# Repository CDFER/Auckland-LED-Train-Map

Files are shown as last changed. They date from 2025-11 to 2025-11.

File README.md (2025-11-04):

# Auckland Live LED Train Map




**You can now support my work by buying this through my store:** [**https://keastudios.co.nz/store/akl-ltm/**](https://keastudios.co.nz/store/akl-ltm/)

A physical, real-time LED map of the Auckland train network, powered by an ESP32-C3 microcontroller. Train movements are displayed using addressable RGB LEDs, with live data fetched over Wi-Fi.

---

## Table of Contents

- [Auckland Live LED Train Map](#auckland-live-led-train-map)
  - [Table of Contents](#table-of-contents)
  - [Features](#features)
  - [Hardware](#hardware)
  - [PCB Design](#pcb-design)
  - [Software / Firmware](#software--firmware)
  - [Getting Started](#getting-started)
  - [Web Installer](#web-installer)
  - [Links](#links)
  - [Contributing](#contributing)
  - [License](#license)

---

PCB Overview Render

## Features

- **Real-time Train Tracking:** Displays the approximate locations of trains on the Auckland network.
- **Addressable LEDs:** ~150 WS2812B-compatible RGB LEDs (1.6x1.5mm) for a vibrant display.
- **Wi-Fi Connectivity:** ESP32-C3's built-in Wi-Fi fetches live train data.
- **Custom PCB:** Designed for JLCPCB manufacturing limits.
- **Open Source:** Hardware and firmware are open source.

---

## Hardware

- **Microcontroller:** ESP32-C3 (RISC-V, 160 MHz, 4 MB Flash, QFN32)
- **LEDs:** ~150 x XL-1615RGBC-WS2812B (1.6mm x 1.5mm)
- **PCB:** 249mm x 66mm, JLCPCB-friendly
- **Antenna:** On-board PCB antenna ([TI CC2430DB design](https://www.ti.com/lit/ug/swru125/swru125.pdf))

ESP32-C3 PCB Render

Pukekohe PCB Render

---

## PCB Design

- Designed in **KiCad V9.0** using [JLCPCB KiCad Library](https://github.com/CDFER/jlcpcb-kicad-library)
- **View Online:** [Interactive PCB Layout (Kicanvas)](https://kicanvas.org/?github=https%3A%2F%2Fgithub.com%2FCDFER%2FAuckland-LED-Train-Map%2Ftree%2Fmain%2FPCB)
- **Source Files:** `/PCB` directory

Schematic

---

## Software / Firmware

The firmware has been moved to it own repo now and can be found here: [LED-Rails-Firmware](https://github.com/CDFER/LED-Rails-Firmware)

---

## Getting Started

1. **Flash the Firmware:**
   - Use the [Web Installer](https://cdfer.github.io/LED-Rails-Firmware/led-rails.html) (recommended, no drivers needed)
2. **Connect to Wi-Fi:**
   - On first boot, use the web interface to configure Wi-Fi credentials.
3. **Power the Board:**
   - Use a 5V USB-C power supply capable of at least 1A.
4. **Enjoy the Live Map!**

---

## Web Installer

Easily flash the latest firmware to your ESP32-C3 using your browser:

[Open the LED Rails Web Installer](https://cdfer.github.io/LED-Rails-Firmware/led-rails.html)

- Works with Chrome, Edge, or any Web Serial-compatible browser
- Follow on-screen instructions to connect and flash your device

---

## Links

- [Web Installer](https://cdfer.github.io/LED-Rails-Firmware/led-rails.html)
- [Interactive PCB Viewer](https://kicanvas.org/?github=https%3A%2F%2Fgithub.com%2FCDFER%2FAuckland-LED-Train-Map%2Ftree%2Fmain%2FPCB)
- [GTFS Realtime Cache API](https://github.com/CDFER/GTFS-Realtime-Cache-Server)
- [JLCPCB KiCad Library](https://github.com/CDFER/jlcpcb-kicad-library)

---

## Contributing

Contributions are welcome! Open an issue or submit a pull request for improvements, bug fixes, or feature suggestions.

---

## License

This project is released under the GPL-3.0-or-later license.

© 2025 Chris Dirks

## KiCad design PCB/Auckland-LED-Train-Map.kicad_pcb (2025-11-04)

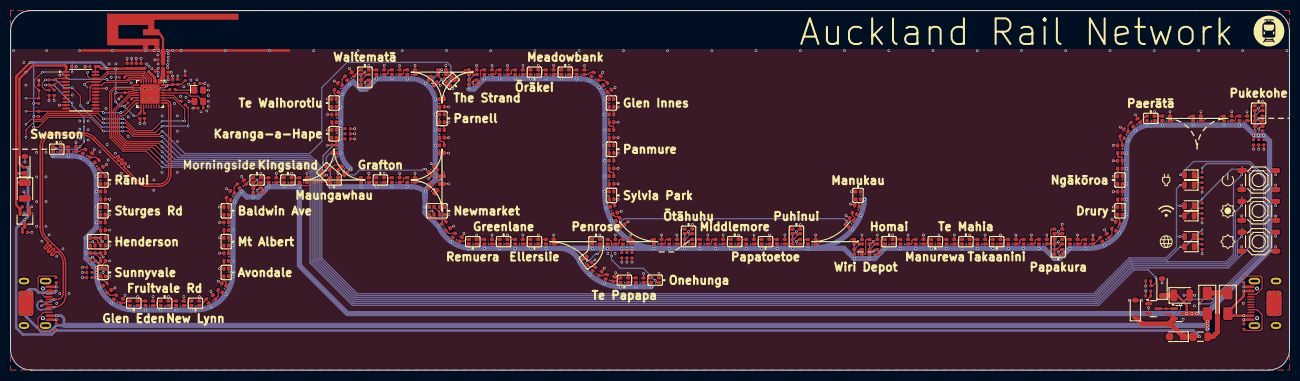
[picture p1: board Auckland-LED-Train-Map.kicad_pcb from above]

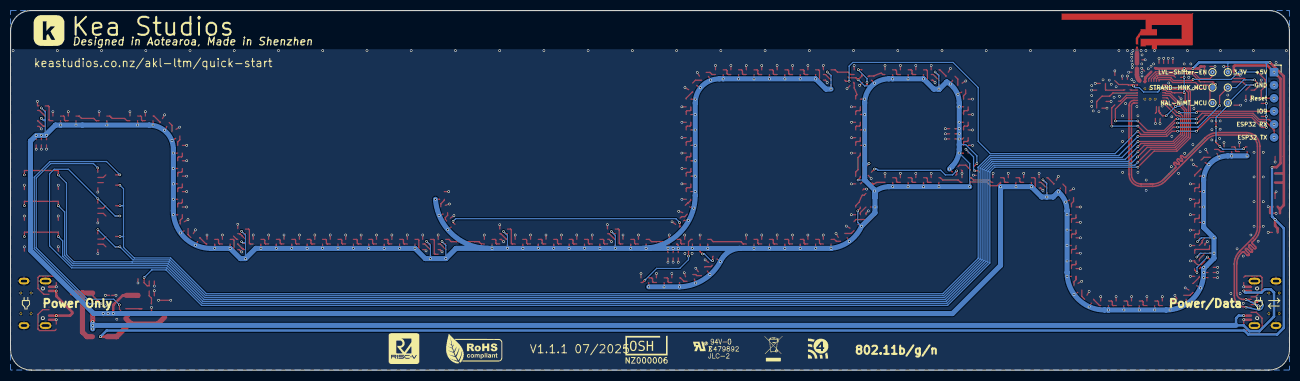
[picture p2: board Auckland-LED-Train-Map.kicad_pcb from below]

Board: 2 copper layers, 249.0 x 70.0 mm, 248 parts (7 on the bottom side), 199 nets.

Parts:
AE1: Antenna_Shield; Inverted_F_Antenna_2.4Ghz_1.0mmPCB_TI_CC2430DB.pretty
C1: 10uF; C_CASE-A-3216-18(mm)
C2, C3, C4, C6, C7, C8, C9, C10, C11, C12, C13, C14, C18, C21, C22, C25, C26, C27, C28, C29, C30, C31, C35, C38, C39, C40, C41, C42, C43: 1uF; C_0402
C5, C15: 100uF; C_CASE-B-3528-21(mm)
C19, C20: 27pF; C_0402
C36, C37: 1.5pF; C_0402
D1: MMSZ5227B; D_SOD-123
D2, D10, D11: Red; D_0805
D4, D5: MM1W5V6; D_SOD-123
D6, D7: SS54; D_SMA
D8, D9, D12: Green; D_0805
D13: H3V3U10B; D_DFN1006-2L
D100, D101, D102, D103, D104, D105, D106, D107, D108, D109, D110, D111, D112, D113, D114, D115, D116, D117, D118, D119, D120, D121, D122, D123, D124, D125, D126, D127, D128, D129, D130, D131, D132, D133, D134, D135, D136, D137, D138, D139, D140, D141, D142, D143, D144, D145, D146, D147, D148, D149, D150, D151, D152, D153, D154, D155, D156, D157, D158, D159, D160, D161, D162, D163, D164, D165, D166, D167, D168, D169, D170, D171, D172, D173, D174, D175, D176, D177, D178, D179, D180, D181, D182, D183, D184, D185, D186, D187, D188, D189, D190, D191, D192, D193, D194, D195, D196, D197, D198, D199, D200, D201, D202, D203, D204, D205, D206, D207, D208, D300, D301, D302, D303, D304, D305, D306, D307, D308, D309, D310, D311, D312, D313, D314, D315, D316, D317, D318, D319, D320, D321, D322, D323, D324, D325, D326, D327, D328, D329, D330, D331, D332, D333, D334, D335, D336, D337, D338, D339, D340, D341, D342, D343, D344: XL-1615RGBC-WS2812B-S; LED-SMD_4P-L1.6-W1.5_XL-1615RGBC-WS2812B
F1: Polyfuse, 2A; Fuse_1206_3216Metric
J1: Prog Connector
L1, L3: 2.7nH; L_0402
L5: 15nH,300mA; L_0402
LOGO1: OSHW-Certification-Mark-Stacked_8x7mm_SilkMask
Q1: HL3415A; Q_SOT-23
Q2: MMBT3904; Q_SOT-23
R1, R2, R3, R4, R8, R12, R17, R21: 10kΩ; R_0402
R7, R18: 510Ω; R_0402
R9, R16, R22, R23, R24, R25: 100kΩ; R_0402
R10, R15: 100Ω; R_0402
R13, R14, R19, R20: 5.1kΩ; R_0402
S1, S2, S3: Tactile Button, 160gf; SW-SMD_4P-L5.1-W5.1-P3.70-LS6.5-TL-2
TP2: NAL-NIMT_MCU; TestPoint_Pad_D1.0mm
TP3: NAL-NIMT_LED; TestPoint_Pad_D1.0mm
TP8: STRAND-MNK_MCU; TestPoint_Pad_D1.0mm
TP9: STRAND-MNK_LED; TestPoint_Pad_D1.0mm
TP13: 3.3V; TestPoint_Pad_D1.0mm
TP15: LVL-Shifter-EN; TestPoint_Pad_D1.0mm
U1: XC6206P332MR; SOT-23-3_L2.9-W1.6-P1.90-LS2.8-BR
U2: ESP32-C3FH4; QFN-32-1EP_5x5mm_P0.5mm_EP3.7x3.7mm_ThermalVias
U3: SN74LVC4245APWR; TSSOP-24_4.4x7.8mm_P0.65mm
U4, U5: Connector, USB-TYPE-C-16P; TYPE-C-SMD_HX-TYPE-C-16PIN
X1: 40MHz, 15pF; OSC-SMD_4P-L3.2-W2.5-BL_SIT8008BI

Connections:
+3V3: C3.1, C4.1, C5.1, C6.1, C8.1, C9.1, C10.1, C11.1, C12.1, C13.1, C22.1, C25.1, D1.1, D8.2, D10.2, D11.2, L3.1, R1.1, R2.1, R3.1, R4.1, TP13.1, U1.2 (VOUT), U2.11 (VDD3P3_RTC), U2.17 (VDD3P3_CPU), U2.31 (VDDA), U2.32 (VDDA), U3.23 (VCCB(3V)), U3.24 (VCCB(3V))
+5V: C15.1, C26.1, C27.1, C28.1, C29.1, C30.1, C31.1, C38.1, C39.1, C40.1, C41.1, C42.1, C43.1, D4.1, D100.2 (VDD), D101.2 (VDD), D102.2 (VDD), D103.2 (VDD), D104.2 (VDD), D105.2 (VDD), D106.2 (VDD), D107.2 (VDD), D108.2 (VDD), D109.2 (VDD), D110.2 (VDD), D111.2 (VDD), D112.2 (VDD), D113.2 (VDD), D114.2 (VDD), D115.2 (VDD), D116.2 (VDD), D117.2 (VDD), D118.2 (VDD), D119.2 (VDD), D120.2 (VDD), D121.2 (VDD), D122.2 (VDD), D123.2 (VDD), D124.2 (VDD), D125.2 (VDD), D126.2 (VDD), D127.2 (VDD), D128.2 (VDD), D129.2 (VDD), D130.2 (VDD), D131.2 (VDD), D132.2 (VDD), D133.2 (VDD), D134.2 (VDD), D135.2 (VDD), D136.2 (VDD), D137.2 (VDD), D138.2 (VDD), D139.2 (VDD), D140.2 (VDD), D141.2 (VDD), D142.2 (VDD), D143.2 (VDD), D144.2 (VDD), D145.2 (VDD), D146.2 (VDD), D147.2 (VDD), D148.2 (VDD), D149.2 (VDD), D150.2 (VDD), D151.2 (VDD), D152.2 (VDD), D153.2 (VDD), D154.2 (VDD), D155.2 (VDD), D156.2 (VDD), D157.2 (VDD), D158.2 (VDD), D159.2 (VDD), D160.2 (VDD), D161.2 (VDD), D162.2 (VDD), D163.2 (VDD), D164.2 (VDD), D165.2 (VDD), D166.2 (VDD), D167.2 (VDD), D168.2 (VDD), D169.2 (VDD), D170.2 (VDD), D171.2 (VDD), D172.2 (VDD), D173.2 (VDD), D174.2 (VDD), D175.2 (VDD), D176.2 (VDD), D177.2 (VDD), D178.2 (VDD), D179.2 (VDD), D180.2 (VDD), D181.2 (VDD), D182.2 (VDD), D183.2 (VDD), D184.2 (VDD), D185.2 (VDD), D186.2 (VDD), D187.2 (VDD), D188.2 (VDD), D189.2 (VDD), D190.2 (VDD), D191.2 (VDD), D192.2 (VDD), D193.2 (VDD), D194.2 (VDD), D195.2 (VDD), D196.2 (VDD), D197.2 (VDD), D198.2 (VDD), D199.2 (VDD), D200.2 (VDD), D201.2 (VDD), D202.2 (VDD), D203.2 (VDD), D204.2 (VDD), D205.2 (VDD), D206.2 (VDD), D207.2 (VDD), D208.2 (VDD), D300.2 (VDD), D301.2 (VDD), D302.2 (VDD), D303.2 (VDD), D304.2 (VDD), D305.2 (VDD), D306.2 (VDD), D307.2 (VDD), D308.2 (VDD), D309.2 (VDD), D310.2 (VDD), D311.2 (VDD), D312.2 (VDD), D313.2 (VDD), D314.2 (VDD), D315.2 (VDD), D316.2 (VDD), D317.2 (VDD), D318.2 (VDD), D319.2 (VDD), D320.2 (VDD), D321.2 (VDD), D322.2 (VDD), D323.2 (VDD), D324.2 (VDD), D325.2 (VDD), D326.2 (VDD), D327.2 (VDD), D328.2 (VDD), D329.2 (VDD), D330.2 (VDD), D331.2 (VDD), D332.2 (VDD), D333.2 (VDD), D334.2 (VDD), D335.2 (VDD), D336.2 (VDD), D337.2 (VDD), D338.2 (VDD), D339.2 (VDD), D340.2 (VDD), D341.2 (VDD), D342.2 (VDD), D343.2 (VDD), D344.2 (VDD), Q1.3 (D)
/+BRIGHTNESS_BUTTON: S2.1 (A), S2.2 (B), U2.13 (MTDO)
/-BRIGHTNESS_BUTTON: S3.1 (A), S3.2 (B), U2.12 (MTCK)
/Antenna: C36.1, D13.2, L1.1, U2.1 (LNA_IN)
/BOOT_IO9_BUTTON: J1.4, R1.2, S1.1 (A), S1.2 (B), U2.15 (GPIO9)
/CONFIG_LED: D12.2, R21.1, U2.10 (MTDI)
/D+: U2.26 (GPIO19/USB_D+), U4.A6 (D+), U4.B6 (D+)
/D-: U2.25 (GPIO18/USB_D-), U4.A7 (D-), U4.B7 (D-)
/LED_+5V_EN_Active_High: R17.1, R18.1, U2.9 (MTMS)
/LVL_Shifter_EN_Active_Low: TP15.1, U2.4 (GPIO0/XTAL_32K_P), U3.22 (OE#)
/MCU_RX: J1.5, U2.27 (U0RXD)
/MCU_TX: J1.6, R7.1
/NAL-NIMT_MCU: TP2.1, U2.8 (GPIO3), U3.20 (B2)
/Reset: C14.1, J1.3, R4.2, U2.7 (CHIP_EN)
/STRAND-MNK_MCU: TP8.1, U2.5 (GPIO1/XTAL_32K_N), U3.21 (B1)
/WIFI_LED: D9.2, R8.1, U2.16 (GPIO10)
GND: AE1.2 (Shield), C1.2, C2.2, C3.2, C4.2, C5.2, C6.2, C7.2, C8.2, C9.2, C10.2, C11.2, C12.2, C13.2, C14.2, C15.2, C18.2, C19.1, C20.2, C21.2, C22.2, C25.2, C26.2, C27.2, C28.2, C29.2, C30.2, C31.2, C35.2, C36.2, C37.2, C38.2, C39.2, C40.2, C41.2, C42.2, C43.2, D1.2, D4.2, D5.2, D13.1, D100.3 (GND), D101.3 (GND), D102.3 (GND), D103.3 (GND), D104.3 (GND), D105.3 (GND), D106.3 (GND), D107.3 (GND), D108.3 (GND), D109.3 (GND), D110.3 (GND), D111.3 (GND), D112.3 (GND), D113.3 (GND), D114.3 (GND), D115.3 (GND), D116.3 (GND), D117.3 (GND), D118.3 (GND), D119.3 (GND), D120.3 (GND), D121.3 (GND), D122.3 (GND), D123.3 (GND), D124.3 (GND), D125.3 (GND), D126.3 (GND), D127.3 (GND), D128.3 (GND), D129.3 (GND), D130.3 (GND), D131.3 (GND), D132.3 (GND), D133.3 (GND), D134.3 (GND), D135.3 (GND), D136.3 (GND), D137.3 (GND), D138.3 (GND), D139.3 (GND), D140.3 (GND), D141.3 (GND), D142.3 (GND), D143.3 (GND), D144.3 (GND), D145.3 (GND), D146.3 (GND), D147.3 (GND), D148.3 (GND), D149.3 (GND), D150.3 (GND), D151.3 (GND), D152.3 (GND), D153.3 (GND), D154.3 (GND), D155.3 (GND), D156.3 (GND), D157.3 (GND), D158.3 (GND), D159.3 (GND), D160.3 (GND), D161.3 (GND), D162.3 (GND), D163.3 (GND), D164.3 (GND), D165.3 (GND), D166.3 (GND), D167.3 (GND), D168.3 (GND), D169.3 (GND), D170.3 (GND), D171.3 (GND), D172.3 (GND), D173.3 (GND), D174.3 (GND), D175.3 (GND), D176.3 (GND), D177.3 (GND), D178.3 (GND), D179.3 (GND), D180.3 (GND), D181.3 (GND), D182.3 (GND), D183.3 (GND), D184.3 (GND), D185.3 (GND), D186.3 (GND), D187.3 (GND), D188.3 (GND), D189.3 (GND), D190.3 (GND), D191.3 (GND), D192.3 (GND), D193.3 (GND), D194.3 (GND), D195.3 (GND), D196.3 (GND), D197.3 (GND), D198.3 (GND), D199.3 (GND), D200.3 (GND), D201.3 (GND), D202.3 (GND), D203.3 (GND), D204.3 (GND), D205.3 (GND), D206.3 (GND), D207.3 (GND), D208.3 (GND), D300.3 (GND), D301.3 (GND), D302.3 (GND), D303.3 (GND), D304.3 (GND), D305.3 (GND), D306.3 (GND), D307.3 (GND), D308.3 (GND), D309.3 (GND), D310.3 (GND), D311.3 (GND), D312.3 (GND), D313.3 (GND), D314.3 (GND), D315.3 (GND), D316.3 (GND), D317.3 (GND), D318.3 (GND), D319.3 (GND), D320.3 (GND), D321.3 (GND), D322.3 (GND), D323.3 (GND), D324.3 (GND), D325.3 (GND), D326.3 (GND), D327.3 (GND), D328.3 (GND), D329.3 (GND), D330.3 (GND), D331.3 (GND), D332.3 (GND), D333.3 (GND), D334.3 (GND), D335.3 (GND), D336.3 (GND), D337.3 (GND), D338.3 (GND), D339.3 (GND), D340.3 (GND), D341.3 (GND), D342.3 (GND), D343.3 (GND), D344.3 (GND), J1.2, Q2.2 (E), R9.2, R13.2, R14.2, R17.2, R19.2, R20.2, R22.2, R23.2, R24.2, R25.2, S1.3 (C), S1.4 (D), S2.3 (C), S2.4 (D), S3.3 (C), S3.4 (D), U1.1 (GND), U2.33 (GND), U3.2 (DIR), U3.11 (GND), U3.12 (GND), U3.13 (GND), U3.14 (B8), U3.15 (B7), U3.16 (B6), U3.17 (B5), U3.18 (B4), U3.19 (B3), U4.A12B1 (GND), U4.B12A1 (GND), U4.S1 (SHIELD), U5.A12B1 (GND), U5.B12A1 (GND), U5.S1 (SHIELD), X1.2 (GND), X1.4 (GND)
NAL-NIMT-1: D100.4 (DIN), R10.1, R24.1, TP3.1
NAL-NIMT-2: D135.1 (DOUT), D136.4 (DIN)
NAL-NIMT-3: D165.1 (DOUT), D166.4 (DIN)
NAL-NIMT-4: D192.1 (DOUT), D193.4 (DIN)
unnamed: AE1.1 (A), C37.1, L1.2
unnamed: C7.1, L3.2, U2.2 (VDD3P3), U2.3 (VDD3P3)
unnamed: C20.1, L5.1, X1.1 (OSC)
unnamed: D2.1, R12.1
unnamed: D2.2, D6.1, D7.1, F1.1
unnamed: D6.2, U4.A9B4 (VBUS), U4.B9A4 (VBUS)
unnamed: D7.2, U5.A9B4 (VBUS), U5.B9A4 (VBUS)
unnamed: D8.1, R9.1
unnamed: D9.1, R22.1
unnamed: D10.1, R8.2
unnamed: D11.1, R21.2
unnamed: D12.1, R23.1
unnamed: D100.1 (DOUT), D101.4 (DIN)
unnamed: D101.1 (DOUT), D102.4 (DIN)
unnamed: D102.1 (DOUT), D103.4 (DIN)
unnamed: D103.1 (DOUT), D104.4 (DIN)
unnamed: D104.1 (DOUT), D105.4 (DIN)
unnamed: D105.1 (DOUT), D106.4 (DIN)
unnamed: D106.1 (DOUT), D107.4 (DIN)
unnamed: D107.1 (DOUT), D108.4 (DIN)
unnamed: D108.1 (DOUT), D109.4 (DIN)
unnamed: D109.1 (DOUT), D110.4 (DIN)
unnamed: D110.1 (DOUT), D111.4 (DIN)
unnamed: D111.1 (DOUT), D112.4 (DIN)
unnamed: D112.1 (DOUT), D113.4 (DIN)
unnamed: D113.1 (DOUT), D114.4 (DIN)
unnamed: D114.1 (DOUT), D115.4 (DIN)
unnamed: D115.1 (DOUT), D116.4 (DIN)
unnamed: D116.1 (DOUT), D117.4 (DIN)
unnamed: D117.1 (DOUT), D118.4 (DIN)
unnamed: D118.1 (DOUT), D119.4 (DIN)
unnamed: D119.1 (DOUT), D120.4 (DIN)
unnamed: D120.1 (DOUT), D121.4 (DIN)
unnamed: D121.1 (DOUT), D122.4 (DIN)
unnamed: D122.1 (DOUT), D123.4 (DIN)
unnamed: D123.1 (DOUT), D124.4 (DIN)
unnamed: D124.1 (DOUT), D125.4 (DIN)
unnamed: D125.1 (DOUT), D126.4 (DIN)
unnamed: D126.1 (DOUT), D127.4 (DIN)
unnamed: D127.1 (DOUT), D128.4 (DIN)
unnamed: D128.1 (DOUT), D129.4 (DIN)
unnamed: D129.1 (DOUT), D130.4 (DIN)
unnamed: D130.1 (DOUT), D131.4 (DIN)
unnamed: D131.1 (DOUT), D132.4 (DIN)
unnamed: D132.1 (DOUT), D133.4 (DIN)
unnamed: D133.1 (DOUT), D134.4 (DIN)
unnamed: D134.1 (DOUT), D135.4 (DIN)
unnamed: D136.1 (DOUT), D137.4 (DIN)
unnamed: D137.1 (DOUT), D138.4 (DIN)
unnamed: D138.1 (DOUT), D139.4 (DIN)
unnamed: D139.1 (DOUT), D140.4 (DIN)
unnamed: D140.1 (DOUT), D141.4 (DIN)
unnamed: D141.1 (DOUT), D142.4 (DIN)
unnamed: D142.1 (DOUT), D143.4 (DIN)
unnamed: D143.1 (DOUT), D144.4 (DIN)
unnamed: D144.1 (DOUT), D145.4 (DIN)
unnamed: D145.1 (DOUT), D146.4 (DIN)
unnamed: D146.1 (DOUT), D147.4 (DIN)
unnamed: D147.1 (DOUT), D148.4 (DIN)
unnamed: D148.1 (DOUT), D149.4 (DIN)
unnamed: D149.1 (DOUT), D150.4 (DIN)
unnamed: D150.1 (DOUT), D151.4 (DIN)
unnamed: D152.1 (DOUT), D153.4 (DIN)
unnamed: D153.1 (DOUT), D154.4 (DIN)
unnamed: D154.1 (DOUT), D155.4 (DIN)
unnamed: D155.1 (DOUT), D156.4 (DIN)
unnamed: D157.1 (DOUT), D158.4 (DIN)
unnamed: D158.1 (DOUT), D159.4 (DIN)
unnamed: D159.1 (DOUT), D160.4 (DIN)
unnamed: D160.1 (DOUT), D161.4 (DIN)
unnamed: D161.1 (DOUT), D162.4 (DIN)
unnamed: D162.1 (DOUT), D163.4 (DIN)
unnamed: D163.1 (DOUT), D164.4 (DIN)
unnamed: D164.1 (DOUT), D165.4 (DIN)
unnamed: D166.1 (DOUT), D167.4 (DIN)
unnamed: D167.1 (DOUT), D168.4 (DIN)
unnamed: D168.1 (DOUT), D169.4 (DIN)
unnamed: D169.1 (DOUT), D170.4 (DIN)
unnamed: D170.1 (DOUT), D171.4 (DIN)
unnamed: D171.1 (DOUT), D172.4 (DIN)
unnamed: D172.1 (DOUT), D173.4 (DIN)
unnamed: D173.1 (DOUT), D174.4 (DIN)
unnamed: D174.1 (DOUT), D175.4 (DIN)
unnamed: D175.1 (DOUT), D176.4 (DIN)
unnamed: D176.1 (DOUT), D177.4 (DIN)
unnamed: D177.1 (DOUT), D178.4 (DIN)
unnamed: D178.1 (DOUT), D179.4 (DIN)
unnamed: D179.1 (DOUT), D180.4 (DIN)
unnamed: D180.1 (DOUT), D181.4 (DIN)
unnamed: D181.1 (DOUT), D182.4 (DIN)
unnamed: D182.1 (DOUT), D183.4 (DIN)
unnamed: D183.1 (DOUT), D184.4 (DIN)
unnamed: D184.1 (DOUT), D185.4 (DIN)
unnamed: D185.1 (DOUT), D186.4 (DIN)
unnamed: D186.1 (DOUT), D187.4 (DIN)
unnamed: D187.1 (DOUT), D188.4 (DIN)
unnamed: D188.1 (DOUT), D189.4 (DIN)
unnamed: D189.1 (DOUT), D190.4 (DIN)
unnamed: D190.1 (DOUT), D191.4 (DIN)
unnamed: D191.1 (DOUT), D192.4 (DIN)
unnamed: D193.1 (DOUT), D194.4 (DIN)
unnamed: D194.1 (DOUT), D195.4 (DIN)
unnamed: D195.1 (DOUT), D196.4 (DIN)
unnamed: D196.1 (DOUT), D197.4 (DIN)
unnamed: D197.1 (DOUT), D198.4 (DIN)
unnamed: D198.1 (DOUT), D199.4 (DIN)
unnamed: D199.1 (DOUT), D200.4 (DIN)
unnamed: D200.1 (DOUT), D201.4 (DIN)
unnamed: D201.1 (DOUT), D202.4 (DIN)
unnamed: D202.1 (DOUT), D203.4 (DIN)
unnamed: D203.1 (DOUT), D204.4 (DIN)
unnamed: D204.1 (DOUT), D205.4 (DIN)
unnamed: D205.1 (DOUT), D206.4 (DIN)
unnamed: D206.1 (DOUT), D207.4 (DIN)
unnamed: D207.1 (DOUT), D208.4 (DIN)
unnamed: D300.1 (DOUT), D301.4 (DIN)
unnamed: D301.1 (DOUT), D302.4 (DIN)
unnamed: D302.1 (DOUT), D303.4 (DIN)
unnamed: D303.1 (DOUT), D304.4 (DIN)
unnamed: D304.1 (DOUT), D305.4 (DIN)
unnamed: D305.1 (DOUT), D306.4 (DIN)
unnamed: D306.1 (DOUT), D307.4 (DIN)
unnamed: D307.1 (DOUT), D308.4 (DIN)
unnamed: D308.1 (DOUT), D309.4 (DIN)
unnamed: D309.1 (DOUT), D310.4 (DIN)
unnamed: D310.1 (DOUT), D311.4 (DIN)
unnamed: D311.1 (DOUT), D312.4 (DIN)
unnamed: D312.1 (DOUT), D313.4 (DIN)
unnamed: D313.1 (DOUT), D314.4 (DIN)
unnamed: D314.1 (DOUT), D315.4 (DIN)
unnamed: D315.1 (DOUT), D316.4 (DIN)
unnamed: D316.1 (DOUT), D317.4 (DIN)
unnamed: D317.1 (DOUT), D318.4 (DIN)
unnamed: D318.1 (DOUT), D319.4 (DIN)
unnamed: D319.1 (DOUT), D320.4 (DIN)
unnamed: D320.1 (DOUT), D321.4 (DIN)
unnamed: D321.1 (DOUT), D322.4 (DIN)
unnamed: D322.1 (DOUT), D323.4 (DIN)
unnamed: D323.1 (DOUT), D324.4 (DIN)
unnamed: D324.1 (DOUT), D325.4 (DIN)
unnamed: D325.1 (DOUT), D326.4 (DIN)
unnamed: D326.1 (DOUT), D327.4 (DIN)
unnamed: D327.1 (DOUT), D328.4 (DIN)
unnamed: D328.1 (DOUT), D329.4 (DIN)
unnamed: D329.1 (DOUT), D330.4 (DIN)
unnamed: D330.1 (DOUT), D331.4 (DIN)
unnamed: D331.1 (DOUT), D332.4 (DIN)
unnamed: D332.1 (DOUT), D333.4 (DIN)
unnamed: D333.1 (DOUT), D334.4 (DIN)
unnamed: D334.1 (DOUT), D335.4 (DIN)
unnamed: D335.1 (DOUT), D336.4 (DIN)
unnamed: D336.1 (DOUT), D337.4 (DIN)
unnamed: D337.1 (DOUT), D338.4 (DIN)
unnamed: D338.1 (DOUT), D339.4 (DIN)
unnamed: D339.1 (DOUT), D340.4 (DIN)
unnamed: D341.1 (DOUT), D342.4 (DIN)
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

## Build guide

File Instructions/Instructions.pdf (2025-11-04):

# Care

# Specifications

Avoid exposure to extreme temperatures and abrasive materials like sand.

Never expose the train map to water. If it has been in contact with water do not try to dry it in rice. Keep it powered off and place it in a warm dry place (less than 80°C) for at least a few days before powering it on again.

You can clean the train map using ≥95% isopropyl alcohol and a clean lint free cloth (only while the device is unpowered).

If you want to take this map on the go, you can connect it to your phone's WiFi hotspot and use a USB battery bank to power it.

Requires 5V ≥ 1A via USB Type C
Works with both USB C-C and A-C Cables Supports WiFi 4 (802.11b/g/n, 2.4Ghz)
Data ≈ 0.1 Gigabytes per month
Power ≈ 0.2-0.5kWh per month ≈ $0.07-0.18 RoHS (Lead Free)

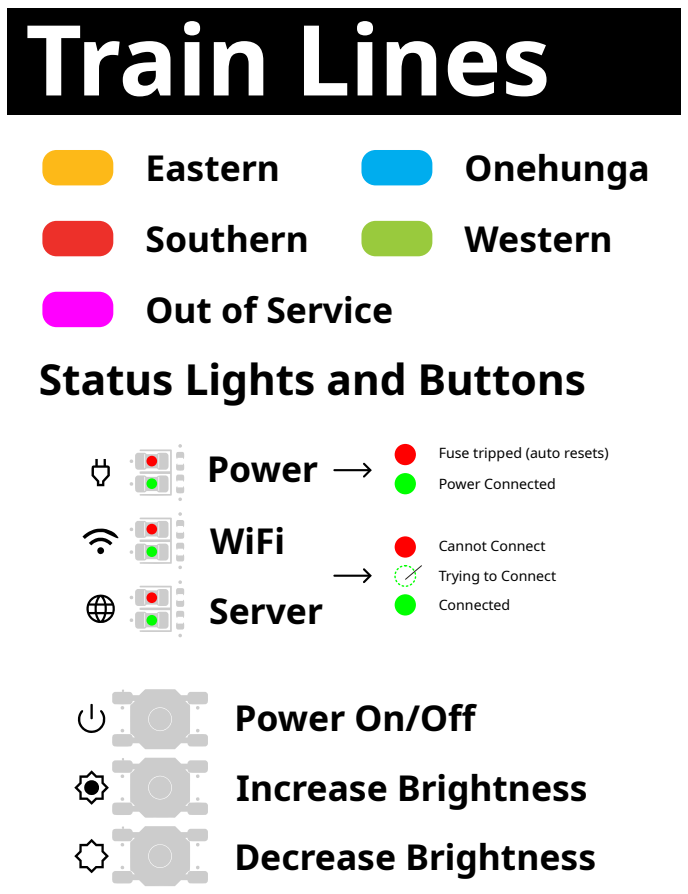
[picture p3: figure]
Train Lines; Status Lights and Buttons; Eastern; Southern; Western; Onehunga; Out of Service; Power WiFi Server; Power On/Off Increase Brightness Decrease Brightness; Fuse tripped (auto resets); Power Connected; Cannot Connect; Trying to Connect; Connected

For the latest Quick Start Guide: keastudios.co.nz/akl-ltm-quick-start/

Firefox and Safari currently don’t work because they don't have web-serial support

For WiFi Setup you must use the left USB-C connector (The right one is power only)

Click on your device and then click Connect in the pop-up to grant device access. If multiple devices appear, look for: USB JTAG/serial debug unit

# Setup

### 2. Open a browser (e.g. Chrome) and go to:

keastudios.co.nz/wt

### 3. Select Firmware (Auckland V1.1) and

Click Connect

### 4. Allow Serial Port Access

Click Change WiFi in the LED-Rails Firmware pop-up window and select your WiFi from the drop down and then enter the password for your WiFi.

### 5. Connect to your WiFi Network

### 1. Connect the train map to your

computer with the supplied USB Cable.

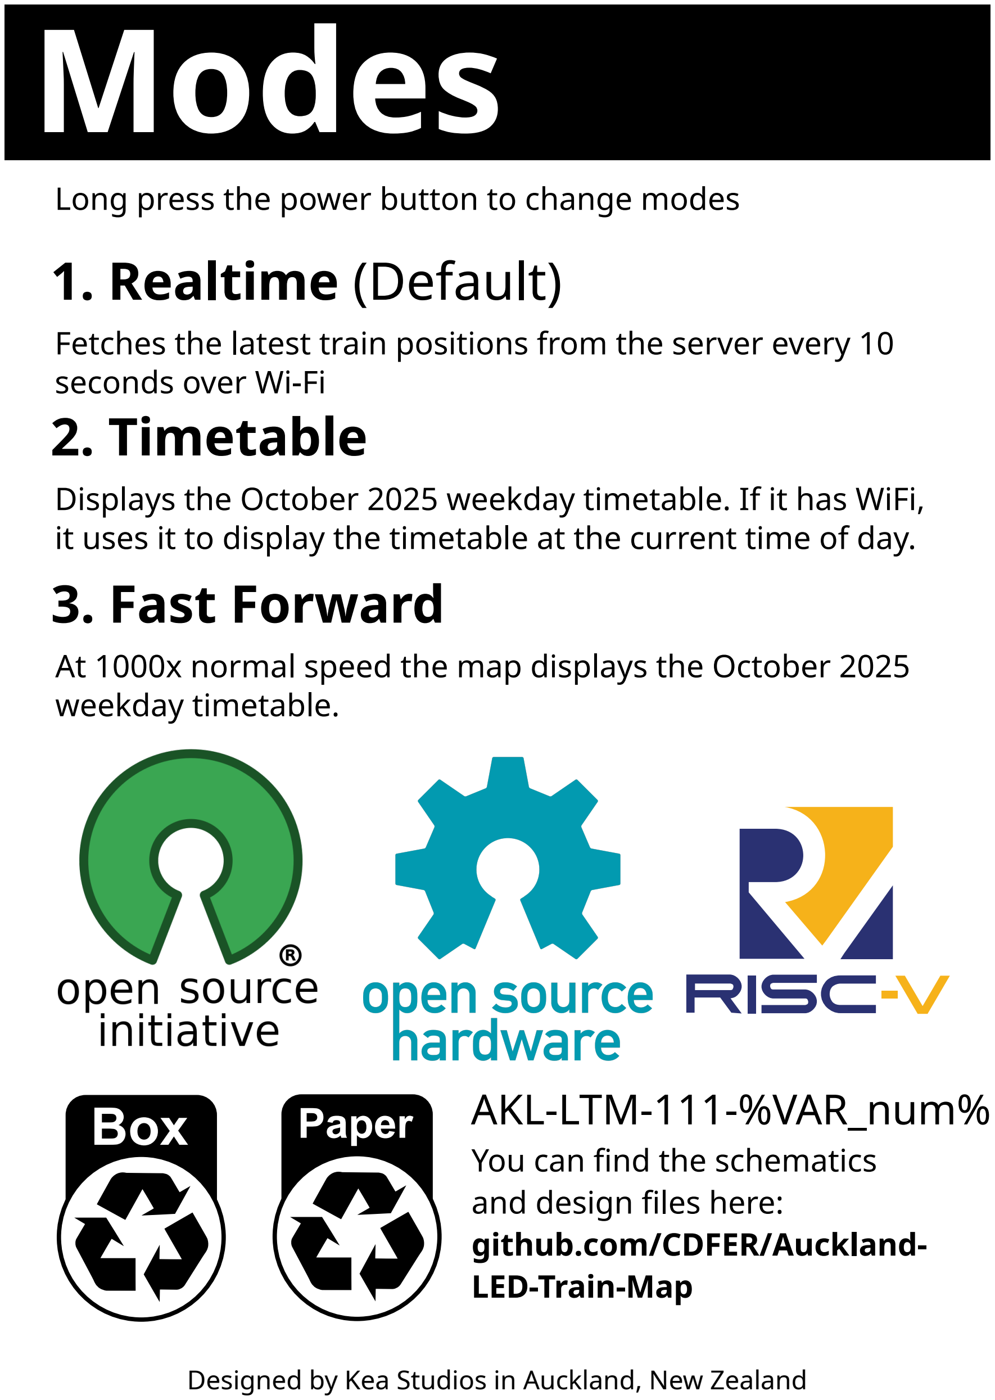
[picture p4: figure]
Modes; AKL-LTM-111-%VAR_num% Box; Paper; E-Waste Only; You can find the schematics and design files here: github.com/CDFER/Auckland- LED-Train-Map; 1. Realtime (Default); seconds over Wi-Fi 2. Timetable; 3. Fast Forward; weekday timetable.

Designed by Kea Studios in Auckland, New Zealand

Fetches the latest train positions from the server every 10

Long press the power button to change modes

Displays the October 2025 weekday timetable. If it has WiFi, it uses it to display the timetable at the current time of day.

At 1000x normal speed the map displays the October 2025

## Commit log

2025-06-07 PCB Checkpoint
    [Auckland-LED-Train-Map.kicad_sch]
2025-06-15 Finish V1.1 PCB
    [Auckland-LED-Train-Map.kicad_sch]
2025-11-04 Remove firmware folder and update readme
    [Auckland-LED-Train-Map.kicad_pcb, default_4MB.csv]

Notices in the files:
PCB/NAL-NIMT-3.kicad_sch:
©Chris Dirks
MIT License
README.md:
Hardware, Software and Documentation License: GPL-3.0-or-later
